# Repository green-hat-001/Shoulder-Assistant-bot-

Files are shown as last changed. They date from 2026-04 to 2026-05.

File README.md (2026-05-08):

# Companion Spider Bot



## Overview
This is a fully custom, 12-DOF quadruped companion robot. This was made to make school and general life a lot more fun and streamlined. This bot will connect to my NAS and be able to transcribe and capture relevant pictures during lectures to be reviewed later. It can also act as an auxiliary screen, and the reason I have made this into a bot is that I wanted to mimic Ankis Cosmo and have that sort of fun and quirky factor to this.

##  Key Features
* **12-DOF Quadrupedal Locomotion:** Powered by 12x MG90S metal gear micro servos, offering 3 degrees of freedom per leg for inverse kinematics-driven walking gaits.
* **Custom "Chip-Down" Mainboard:** A integrated custom PCB built around the ESP32-S3-WROOM-1 module, keeping the electronics profile incredibly thin.
* **Intelligent Power Delivery:** * Simultaneous charge-and-play capability via USB-C.
* **Computer Vision:** Integrated OV2640 camera module for AI-driven object recognition and tracking.

##  Hardware Bill of Materials (BOM)

### Electronics & Brain
* **Microcontroller:** ESP32-S3-WROOM-1 (Custom PCB)
* **Servo Controller:** PCA9685 16-Channel PWM Driver
* **Vision:** OV2640 Camera Module 
* **Custom PCB:** 2-layer custom board (SMT assembled)
* **Intelligent Power Delivery:** * Simultaneous charge-and-play capability via USB-C.
  * IP2326 Boost Module steps 5V up to 8.4V to charge the onboard 2S LiPo.
  * Onboard XL4015 buck converter drops battery voltage to a clean, high-current 5V for the servo array, while an AMS1117 handles 3.3V logic.
  * Schottky diode OR-gate ensures the ESP32-S3 remains safely powered via USB during programming, even when the battery is disconnected.

### Power System
* **Battery:** 2S LiPo (7.4V, 2000mAh, 20C) with XT30 connector
* **Charge Controller:** IP2326 2S Step-Up Module (Modified for raw pad soldering)
* **Voltage Regulation:** XL4015 (5V out for servos), AMS1117 (3.3V out for logic)
* **Smartwatch Integration:** Stripped Samsung Watch 7 charger + logic-level MOSFET

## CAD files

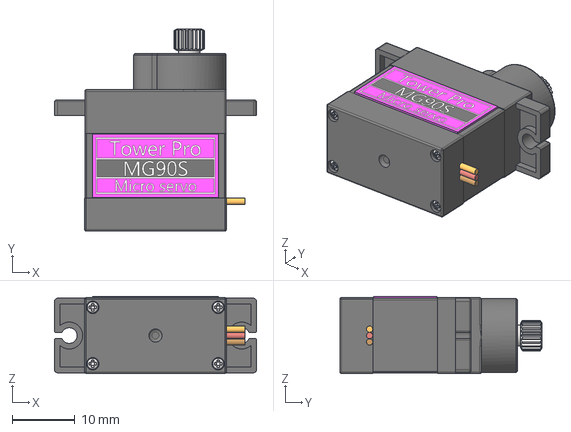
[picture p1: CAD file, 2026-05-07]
CAD/Tower Pro MG90S Micro servo.step
32.2 x 32.2 x 12.3 mm

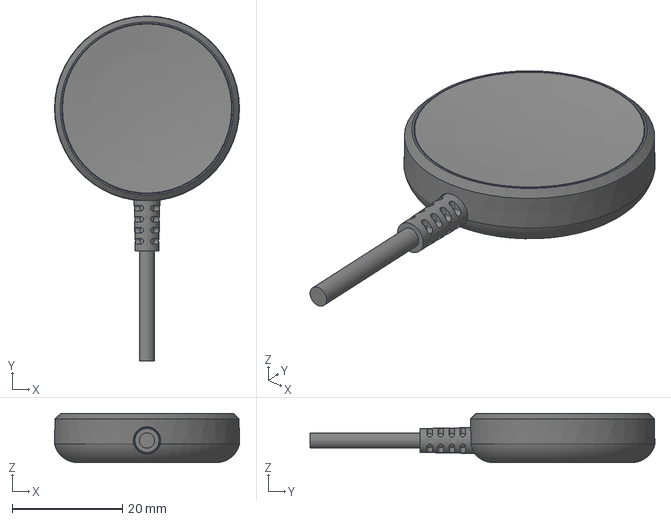
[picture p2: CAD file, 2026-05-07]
CAD/Samsung Watch wireless charger EP-OR825.step
33.6 x 62.6 x 8.90 mm

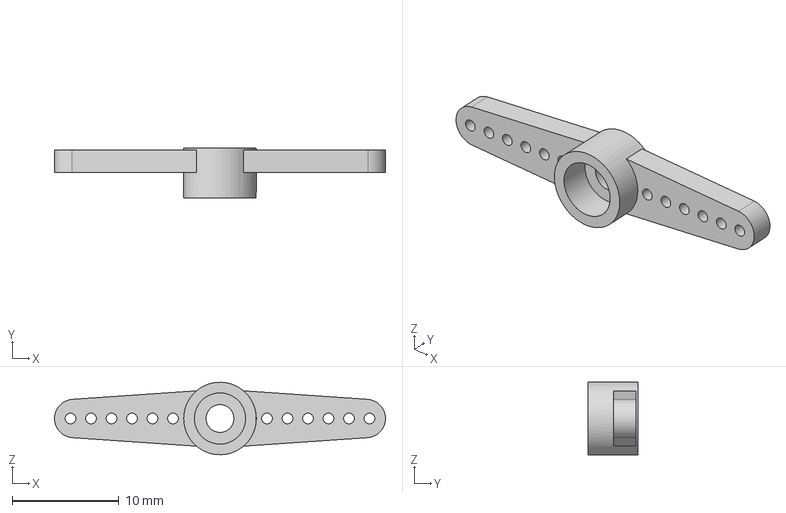
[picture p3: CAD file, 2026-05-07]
CAD/MG90S Servo Horn (2 spork).step
31.0 x 4.70 x 6.80 mm

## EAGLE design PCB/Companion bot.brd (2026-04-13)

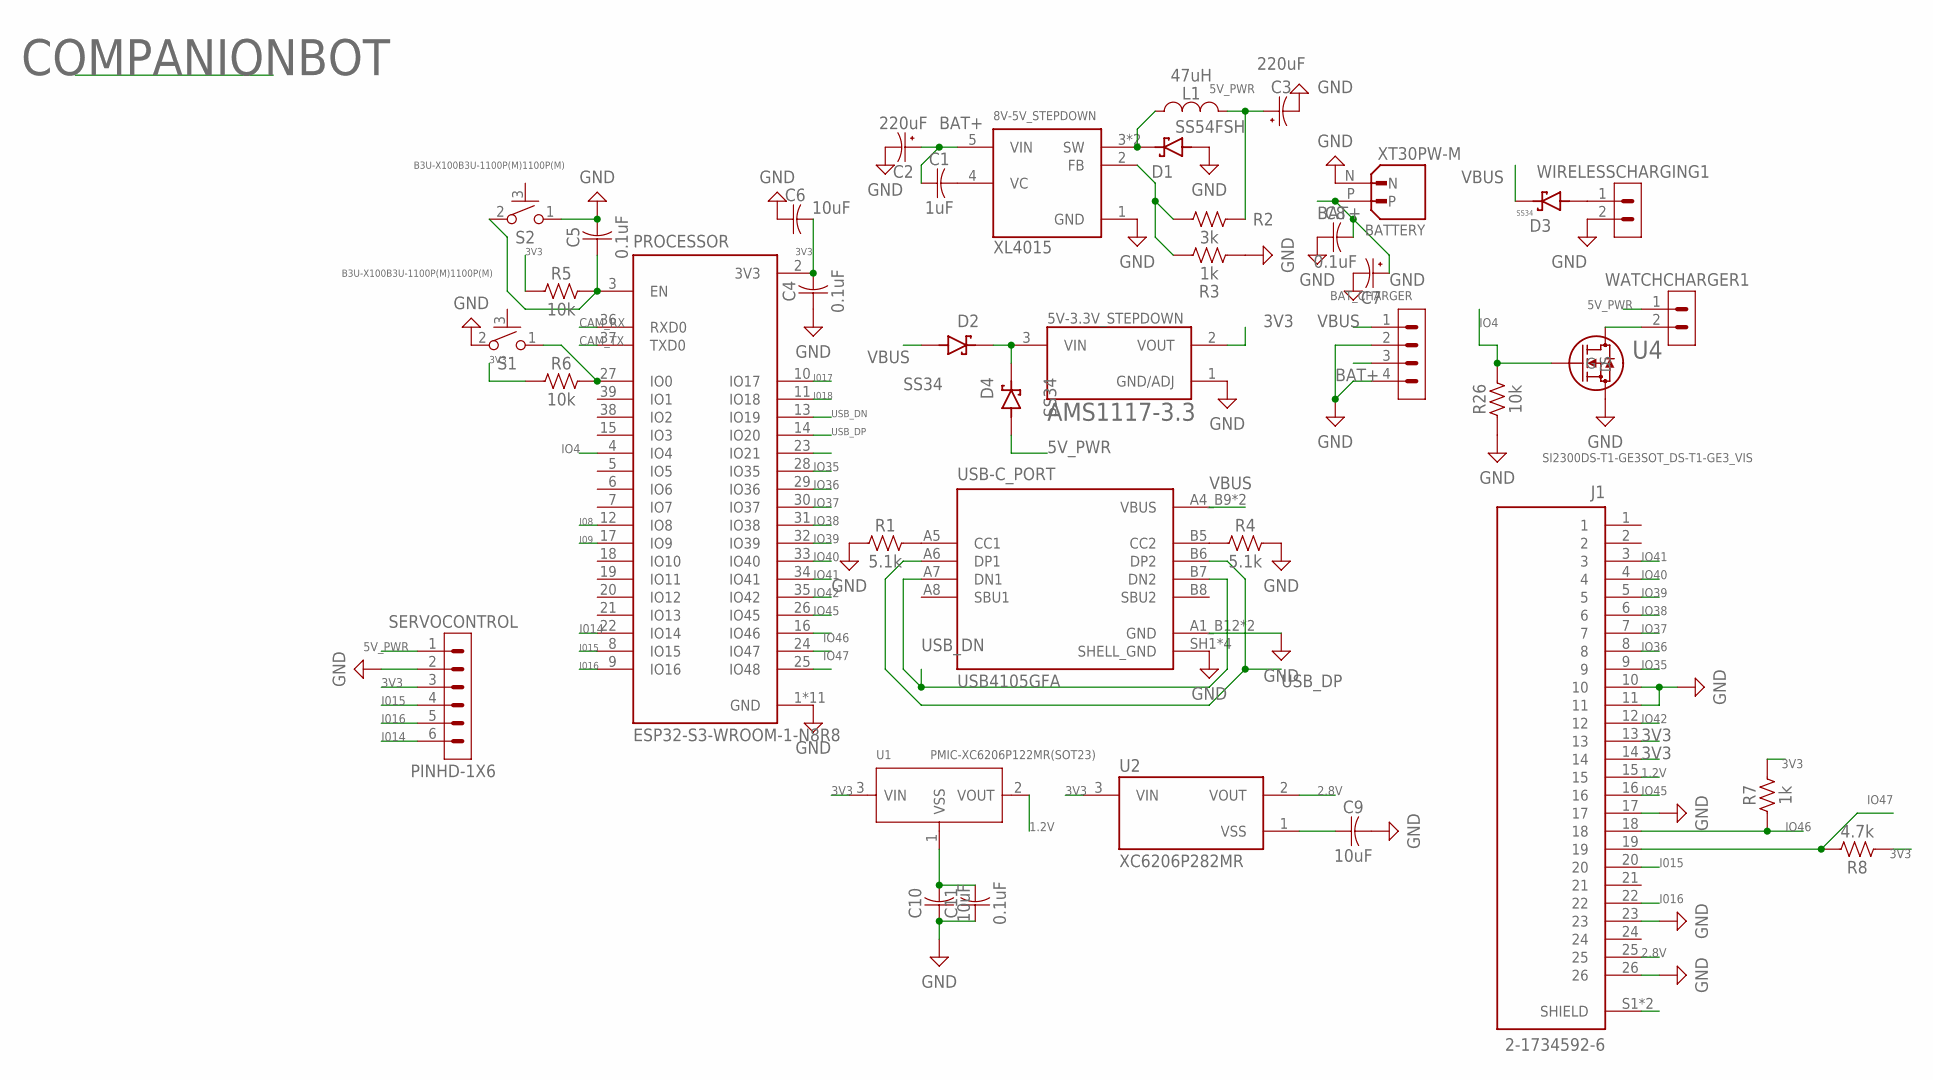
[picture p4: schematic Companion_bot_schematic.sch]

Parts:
5V-3.3V_STEPDOWN: AMS1117-3.3; SOT229P700X180-4N
8V-5V_STEPDOWN: XL4015; CONV_XL4015
BATTERY: XT30PW-M; AMASS_XT30PW-M
BAT_CHARGER: PINHD-1X4; 1X04
C1: 1uF; CAPC1005X60
C2, C3: 220uF; CAPMP3216X180N
C4, C5, C8, C11: 0.1uF; CAPC1005X60
C6, C9, C10: 10uF; CAPC1005X60
C7: C-POL-US_TANTALUM-1206(3216-METRIC); CAPMP3216X180N
D1: SS54FSH; SODFL4725X110N
D2, D3, D4: SS34; DIO_SS34
J1: 2-1734592-6; TE_2-1734592-6
L1: 47uH; INDC1006X60N
PROCESSOR: ESP32-S3-WROOM-1-N8R8; XCVR_ESP32S3WROOM1N8R8
R1, R4: 5.1k; RESC1005X40
R2: 3k; RESC1005X40
R3, R7: 1k; RESC1005X40
R5, R6, R26: 10k; RESC1005X40
R8: 4.7k; RESC1005X40
S1, S2: B3U-X100B3U-1100P(M)1100P(M); B3U-1100P(M)
SERVOCONTROL: PINHD-1X6; 1X06
U1: PMIC-XC6206P122MR(SOT23); SOT-23
U2: XC6206P282MR; VREG_XC6206P282MR
U4: SI2300DS-T1-GE3SOT_DS-T1-GE3_VIS; SOT_DS-T1-GE3_VIS
USB-C_PORT: USB4105GFA; GCT_USB4105GFA
WATCHCHARGER1: PINHD-1X2; 1X02
WIRELESSCHARGING1: PINHD-1X2; 1X02

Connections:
1.2V: J1.15, U1.2 (VOUT)
2.8V: J1.25, U2.2 (VOUT)
3V3: 5V-3.3V_STEPDOWN.2 (VOUT), C4.2, C6.2, J1.13, J1.14, PROCESSOR.2 (3V3), R5.1, R6.1, R7.2, R8.1, SERVOCONTROL.3, U1.3 (VIN), U2.3 (VIN)
5V_PWR: C3.1 (+), D4.A, L1.2, R2.2, SERVOCONTROL.1, WATCHCHARGER1.1
BAT+: 8V-5V_STEPDOWN.5 (VIN), BATTERY.P, BAT_CHARGER.3, C1.1, C2.1 (+), C7.1 (+), C8.2
CAM_RX: PROCESSOR.36 (RXD0)
CAM_TX: PROCESSOR.37 (TXD0)
GND: 5V-3.3V_STEPDOWN.1 (GND/ADJ), 8V-5V_STEPDOWN.1 (GND), BATTERY.N, BAT_CHARGER.2, BAT_CHARGER.4, C2.2 (-), C3.2 (-), C4.1, C5.2, C6.1, C7.2 (-), C8.1, C9.2, C10.1, C11.1, D1.A, J1.10, J1.11, J1.17, J1.23, J1.26, PROCESSOR.1 (GND), PROCESSOR.40 (GND), PROCESSOR.41_1 (GND), PROCESSOR.41_2 (GND), PROCESSOR.41_3 (GND), PROCESSOR.41_4 (GND), PROCESSOR.41_5 (GND), PROCESSOR.41_6 (GND), PROCESSOR.41_7 (GND), PROCESSOR.41_8 (GND), PROCESSOR.41_9 (GND), R1.1, R3.2, R4.2, R26.1, S1.2 (1), S2.1 (2), SERVOCONTROL.2, U4.3 (S), USB-C_PORT.A1_B12 (GND), USB-C_PORT.B1_A12 (GND), USB-C_PORT.SH1 (SHELL_GND), USB-C_PORT.SH2 (SHELL_GND), USB-C_PORT.SH3 (SHELL_GND), USB-C_PORT.SH4 (SHELL_GND), WIRELESSCHARGING1.2
I08: PROCESSOR.12 (IO8)
I09: PROCESSOR.17 (IO9)
I014: PROCESSOR.22 (IO14), SERVOCONTROL.6
I015: J1.20, PROCESSOR.8 (IO15), SERVOCONTROL.4
I016: J1.22, PROCESSOR.9 (IO16), SERVOCONTROL.5
I017: PROCESSOR.10 (IO17)
I018: PROCESSOR.11 (IO18)
IO4: PROCESSOR.4 (IO4), R26.2, U4.1 (G)
IO35: J1.9, PROCESSOR.28 (IO35)
IO36: J1.8, PROCESSOR.29 (IO36)
IO37: J1.7, PROCESSOR.30 (IO37)
IO38: J1.6, PROCESSOR.31 (IO38)
IO39: J1.5, PROCESSOR.32 (IO39)
IO40: J1.4, PROCESSOR.33 (IO40)
IO41: J1.3, PROCESSOR.34 (IO41)
IO42: J1.12, PROCESSOR.35 (IO42)
IO45: J1.16, PROCESSOR.26 (IO45)
IO46: J1.18, PROCESSOR.16 (IO46), R7.1
IO47: J1.19, PROCESSOR.24 (IO47), R8.2
unnamed: R1.2, USB-C_PORT.A5 (CC1)
unnamed: R4.1, USB-C_PORT.B5 (CC2)
unnamed: 8V-5V_STEPDOWN.4 (VC), C1.2
unnamed: 8V-5V_STEPDOWN.3 (SW), 8V-5V_STEPDOWN.3.1 (SW), D1.C (K), L1.1
unnamed: 8V-5V_STEPDOWN.2 (FB), R2.1, R3.1
unnamed: C5.1, PROCESSOR.3 (EN), R5.2, S2.2 (1)
unnamed: PROCESSOR.27 (IO0), R6.2, S1.1 (2)
unnamed: 5V-3.3V_STEPDOWN.3 (VIN), D2.C (K), D4.C (K)
unnamed: C9.1, U2.1 (VSS)
unnamed: U4.2 (D), WATCHCHARGER1.2
unnamed: D3.A, WIRELESSCHARGING1.1
unnamed: J1.S1 (SHIELD), J1.S2 (SHIELD)
USB_DN: PROCESSOR.13 (IO19), USB-C_PORT.A7 (DN1), USB-C_PORT.B7 (DN2)
USB_DP: PROCESSOR.14 (IO20), USB-C_PORT.A6 (DP1), USB-C_PORT.B6 (DP2)
VBUS: BAT_CHARGER.1, D2.A, D3.C (K), USB-C_PORT.A4_B9 (VBUS), USB-C_PORT.B4_A9 (VBUS)
VSS: C10.2, C11.2, U1.1 (VSS)

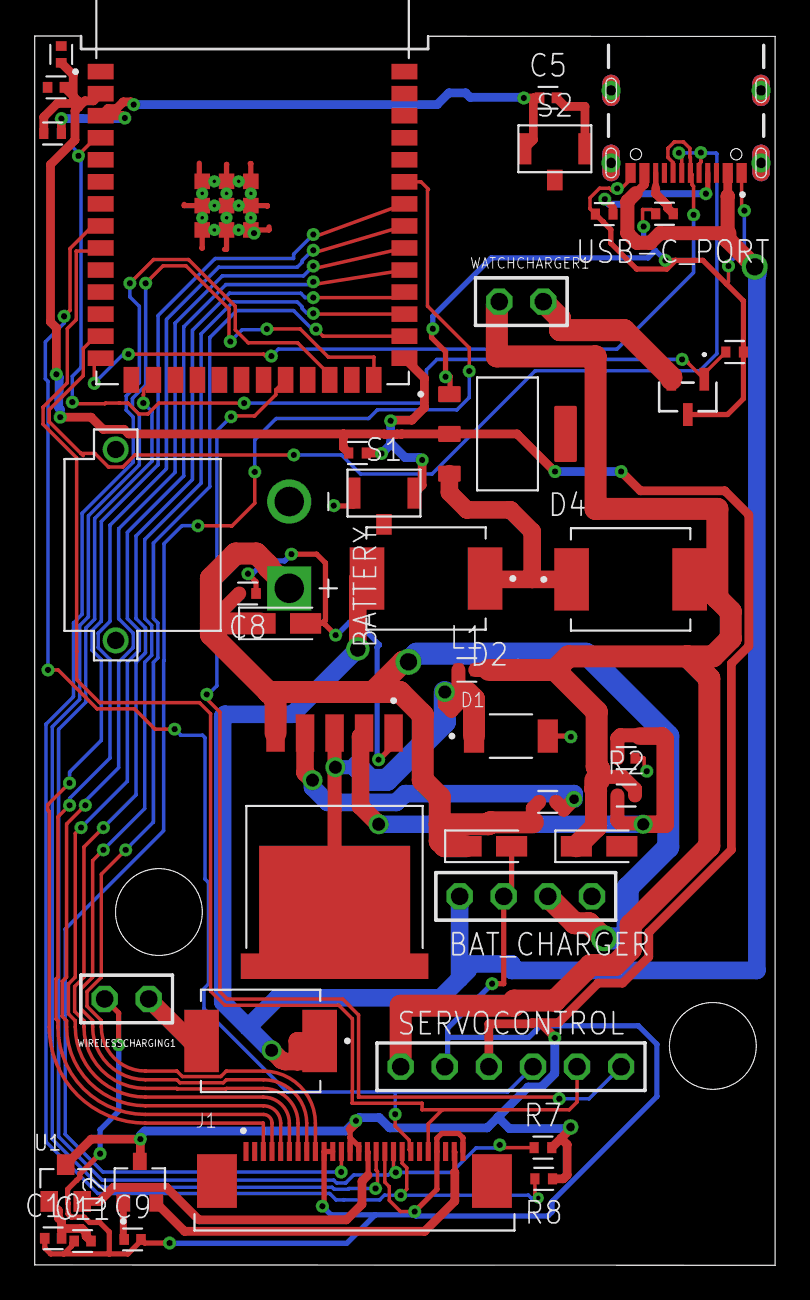
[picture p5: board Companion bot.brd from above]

Board: 2 copper layers, 42.7 x 70.8 mm, 40 parts (0 on the bottom side), 37 nets.

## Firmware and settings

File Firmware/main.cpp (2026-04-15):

#include <Arduino.h>
#include "servo_manager.h"
#include "ik_engine.h"
#include "config.h"
#include "Calibration_server.h"

ServoManager servos;

const float COXA_LENGTH = 30.0;
const float FEMUR_LENGTH = 60.0;
const float TIBIA_LENGTH = 80.0;

IKEngine ik(COXA_LENGTH, FEMUR_LENGTH, TIBIA_LENGTH);

void setup() {
    Serial.begin(115200);
    servos.begin();
    servos.centreAll();
    delay(2000);  // Allow time for serial monitor to initialize

    setupCalibrationServer();
    Serial.println("Connect phone to Wi-Fi: 'SpiderBot_Setup' (Pass: 12345678)");
    Serial.println("Then navigate to 192.168.4.1 in your browser.");

    Serial.println("===============================");
    Serial.println("Phase 1.1: Hardware Verification");
    Serial.println("===============================");

    // Initialize MOSFET pin for the Galaxy Watch charger
    pinMode(WATCH_CHARGER_PIN, OUTPUT);
    digitalWrite(WATCH_CHARGER_PIN, LOW);  // Start with charger OFF
    Serial.println("[Setup] Watch charger MOSFET initialized (OFF).");

    // Initialize I2C and PCA9685
    Serial.println("[Setup] Initializing PCA9685 ServoManager...");
    if (servos.begin()) {
        Serial.println("[Setup] PCA9685 initialized successfully.");
    } else {
        Serial.println("[Setup] ERROR: Failed to find PCA9685!");
        while (1); // Halt system if I2C fails
    }

    // Move all servos to the 90-degree neutral position
    Serial.println("[Setup] Centering all servos to 90 degrees...");
    servos.centreAll();
    delay(1000);
    Serial.println("[Setup] System is ready.");
}

void loop() {
    // Target coordinate: 50mm out, 50mm forward, -60mm down
    float targetX = 50.0;
    float targetY = 50.0;
    float targetZ = -60.0;

    LegAngles targetAngles = ik.calculateIK(targetX, targetY, targetZ);

    if (targetAngles.isValid) {
        Serial.println("[IK] Target coordinates: (" + String(targetX) + ", " + String(targetY) + ", " + String(targetZ) + ")");
        Serial.println("[IK] Calculated Angles - Coxa: " + String(targetAngles.coxa, 2) + "°, Femur: " + String(targetAngles.femur, 2) + "°, Tibia: " + String(targetAngles.tibia, 2) + "°");
    } else {
        Serial.println("[IK] Target coordinates are out of reach for the leg.");
    }

    delay(2000); // Pause before next test phase

    loopCalibrationServer();

    // // =======================================
    // // 1.1 Test A: Single Servo Movement
    // // =======================================
    // Serial.println("[Test A] Sweeping Front Left Tibia (Pin 2)..."); 
    
    // // Sweep up
    // for (int angle = 45; angle <= 135; angle += 5) {
    //     servos.SetAngle(FL_TIBIA, angle);
    //     delay(30); // Fast, smooth sweep
    // }
    
    // // Sweep down
    // for (int angle = 135; angle >= 45; angle -= 5) {
    //     servos.SetAngle(FL_TIBIA, angle);
    //     delay(30);
    // }
    
    // // Return to center
    // servos.SetAngle(FL_TIBIA, 90);
    // Serial.println("[Test A] Servo sweep complete.");
    // delay(1000);

    // // =======================================
    // // 1.1 Test B: MOSFET / Watch Charger Toggle
    // // =======================================
    // Serial.println("[Test B] Toggling Watch Charger MOSFET...");
    
    // Serial.println(">>> Charger ON");
    // digitalWrite(WATCH_CHARGER_PIN, HIGH);
    // delay(3000);  // Leave on for 3 seconds to verify charging ring on watch
    
    // Serial.println(">>> Charger OFF");
    // digitalWrite(WATCH_CHARGER_PIN, LOW);
    // delay(3000);  // Leave off for 3 seconds

    // Serial.println("--- Restarting Diagnostic Loop ---");
}

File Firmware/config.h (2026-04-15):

#ifndef CONFIG_H
#define CONFIG_H

#define I2C_SDA_PINS 8
#define I2C_SCL_PINS 9
#define WATCH_CHARGER_PIN 10

#define PCA9685_ADDRESS 0x40
#define SERVO_FREQ 50

#define SERVO_MIN_PULSE 150
#define SERVO_MAX_PULSE 600

#define FL_COXA 0
#define FL_FEMUR 1
#define FL_TIBIA 2

#define FR_COXA  3
#define FR_FEMUR 4
#define FR_TIBIA 5

#define BL_COXA  6
#define BL_FEMUR 7
#define BL_TIBIA 8

#define BR_COXA  9
#define BR_FEMUR 10
#define BR_TIBIA 11

#endif

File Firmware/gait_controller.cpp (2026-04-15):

#include "gait_controller.h"

GaitController::GaitController(IKEngine* ik_ptr, ServoManager* servos_ptr) {
    ik = ik_ptr;
    servos = servos_ptr;
    isWalking = false;
    currentStep = 0;
    lastUpdateTime = 0;
}

void GaitController::startWalking() {
    isWalking = true;
    currentStep = 0;
}

void GaitController::stopWalking() {
    isWalking = false;
    // Return all legs to a neutral standing stance
    moveLeg(0, STANCE_X, 0, STANCE_Z); // FL
    moveLeg(1, STANCE_X, 0, STANCE_Z); // FR
    moveLeg(2, STANCE_X, 0, STANCE_Z); // BL
    moveLeg(3, STANCE_X, 0, STANCE_Z); // BR
}

void GaitController::update() {
    if (!isWalking) return;

    if (millis() - lastUpdateTime > STEP_DELAY) {
        lastUpdateTime = millis();
        
        executeTrotPhase(currentStep);
        
        currentStep++;
        if (currentStep > 3) currentStep = 0; // Loop the 4 phases
    }
}

// leg_index: 0=FL, 1=FR, 2=BL, 3=BR
void GaitController::moveLeg(uint8_t leg_index, float targetX, float targetY, float targetZ) {
    // We must mirror the math for right-side and back-side legs
    float x = (leg_index == 1 || leg_index == 3) ? -targetX : targetX; 
    float y = (leg_index == 2 || leg_index == 3) ? -targetY : targetY; 
    
    LegAngles angles = ik->calculateIK(abs(x), abs(y), targetZ); // IK only needs absolute magnitudes

    if (angles.isValid) {
        // Map the 3 IK angles to the correct 12 PCA channels based on leg_index
        // FL = 0,1,2 | FR = 3,4,5 | BL = 6,7,8 | BR = 9,10,11
        uint8_t base_channel = leg_index * 3; 
        
        // You may need to invert angles here depending on how your servos are mounted!
        // E.g., servos->SetAngle(base_channel + 1, 180 - angles.femur);
        servos->SetAngle(base_channel, angles.coxa);         // Coxa
        servos->SetAngle(base_channel + 1, angles.femur);    // Femur
        servos->SetAngle(base_channel + 2, angles.tibia);    // Tibia
    }
}

void GaitController::executeTrotPhase(int phase) {
    // Pair 1: Front-Left (0) & Back-Right (3)
    // Pair 2: Front-Right (1) & Back-Left (2)
    
    switch (phase) {
        case 0:
            // Lift Pair 1, Move Forward. Pair 2 pushes back on the ground.
            moveLeg(0, STANCE_X, STRIDE_Y, STANCE_Z + LIFT_Z);  
            moveLeg(3, STANCE_X, STRIDE_Y, STANCE_Z + LIFT_Z);
            
            moveLeg(1, STANCE_X, -STRIDE_Y, STANCE_Z); 
            moveLeg(2, STANCE_X, -STRIDE_Y, STANCE_Z); 
            break;
            
        case 1:
            // Plant Pair 1 down.
            moveLeg(0, STANCE_X, STRIDE_Y, STANCE_Z);  
            moveLeg(3, STANCE_X, STRIDE_Y, STANCE_Z);
            break;
            
        case 2:
            // Lift Pair 2, Move Forward. Pair 1 pushes back on the ground.
            moveLeg(1, STANCE_X, STRIDE_Y, STANCE_Z + LIFT_Z); 
            moveLeg(2, STANCE_X, STRIDE_Y, STANCE_Z + LIFT_Z); 
            
            moveLeg(0, STANCE_X, -STRIDE_Y, STANCE_Z);  
            moveLeg(3, STANCE_X, -STRIDE_Y, STANCE_Z);
            break;
            
        case 3:
            // Plant Pair 2 down.
            moveLeg(1, STANCE_X, STRIDE_Y, STANCE_Z); 
            moveLeg(2, STANCE_X, STRIDE_Y, STANCE_Z); 
            break;
    }
}

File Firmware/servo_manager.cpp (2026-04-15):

#include "servo_manager.h"

ServoManager::ServoManager() : pwm(Adafruit_PWMServoDriver()) {
    for (int i=0; i<12; i++) {
        offsets[i] = 0; // Initialize offsets to zero
    }
}

bool ServoManager::begin() {
    Wire.begin(I2C_SDA_PINS, I2C_SCL_PINS);

    preferences.begin("Calibration", false); // Open preferences with namespace "Calibration"
    for (uint8_t i = 0; i < 12; i++) {
        char key[5];
        sprintf(key, "ch%d", i);
        offsets[i] = preferences.getInt(key, 0); // Load offset for each channel, default to 0
    }

    pwm.begin();
    pwm.setOscillatorFrequency(27000000);  // The default, but can be adjusted
    pwm.setPWMFreq(SERVO_FREQ);  // Analog servos run at ~50 Hz updates

    delay(10);  // Allow time for the PCA9685 to initialize
    return true;
}

uint16_t ServoManager::angleToPulse(float angle) {
    if (angle < 0.0) angle = 0.0;
    if (angle > 180.0) angle = 180.0;
    return map(angle, 0, 180, SERVO_MIN_PULSE, SERVO_MAX_PULSE);
}

void ServoManager::SetAngle(uint8_t channel, float angle) {
    float calibratedAngle = angle + offsets[channel]; // Apply offset
    uint16_t pulse = angleToPulse(angle);
    pwm.setPWM(channel, 0, pulse);
}

void ServoManager::centreAll() {
    for (uint8_t i = 0; i < 12; i++){
        SetAngle(i, 90.0);  // Center position for most servos
    }
}

void ServoManager::setOffset(uint8_t channel, int8_t offset) {
    if(channel < 12) {
        offsets[channel] = offset;
        SetAngle(channel, 90.0); // Immediately update position to visualize it
    }
}

void ServoManager::saveOffsets() {
    for (uint8_t i = 0; i < 12; i++) {
        char key[5];
        sprintf(key, "ch%d", i);
        preferences.putInt(key, offsets[i]);
    }
}

int8_t ServoManager::getOffset(uint8_t channel) {
    return offsets[channel];
}

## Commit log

2026-04-15 Firmware and organisation
    [Companion bot.brd, Companion_bot_schematic.sch]
2026-05-07 Gerber files
2026-05-07 CAD design files
    [MG90S Servo Horn (2 spork).step, Samsung Watch wireless charger EP-OR825.step, Tower Pro MG90S Micro servo.step]

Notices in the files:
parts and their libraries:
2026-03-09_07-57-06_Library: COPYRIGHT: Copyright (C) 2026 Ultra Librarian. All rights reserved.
